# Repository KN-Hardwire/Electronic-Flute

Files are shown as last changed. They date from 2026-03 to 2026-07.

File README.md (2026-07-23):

<div align="center">

# Electronic Flute

### *This repository present HARDWIRE student club [AGH University of Cracow](https://en.wikipedia.org/wiki/AGH_University_of_Krak%C3%B3w) Electronic Flute project.*

---

<a href="https://youtu.be/xWjR7IvugFc" target="_blank">
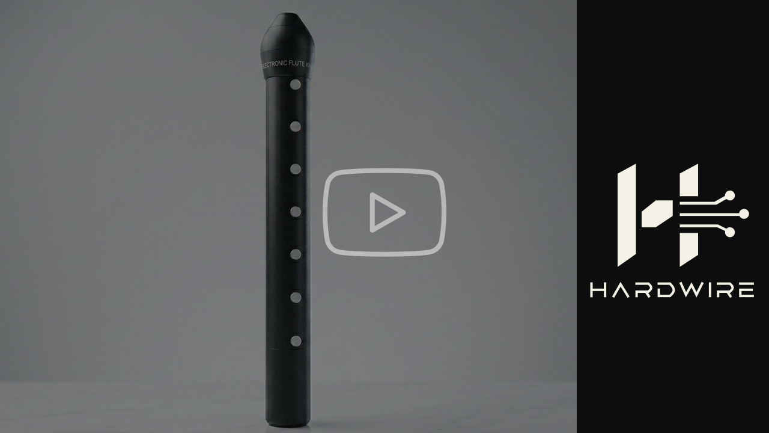
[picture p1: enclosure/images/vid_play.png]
Watch the video
   
</a>
<br />
<em>Watch the video on our YouTube channel to see how it works!</em>

---

</div>

## Programming and assembly

Please refer to guides in each folder for details.

## Playing the flute

All the officially supported note are listed inside the [Fingering Chart](./Fingering_Chart.md), though you should be able to play the instrument just like a standard [recorder flute](https://en.wikipedia.org/wiki/Recorder_(musical_instrument)).

---
<div align="center">
  <sub>Electronic Flute • KN-Hardwire</sub>
</div>

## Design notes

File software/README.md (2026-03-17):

# Software

## Instalation
You can install already compiled firmware on github by going to **Actions**
section and choosing the latest passing commit on the **build** workflow.
There you will find the **'firmware'** binary ready to download.

## Dependencies
- pico-sdk for C/C++ (included as submodule)

## Compilation
To compile the firmware locally you must first:   
Initialize pico-sdk and its submodules:
```
git submodule update --init --recursive
```

Create a build directory and from it run cmake: 
```
mkdir build
cd build
cmake ..
```

There are CMake flags available for easier debugging and development:   
*No debug on default (no flag passed)*
```
-DDEBUG_MODE=<OFF/ON>
```

If succesful, run the Makefile from build directory:
```
make
```

## Flashing
To flash use the SWD Port located on the board.
Use a Rasberry Pi Pico flashed with [debugprobe_on_pico.uf2](https://github.com/raspberrypi/debugprobe/releases)
and make a connection as follows:
| Pico | Flute |
| --- | --- |
| GND | GND |
| CLK | GP2 |
| S_IO | GP3 |

Alternatively you can use a dedicated Rasberry Pi Debugprobe.

Then to upload the code, **with the 3V battery installed**, inside build folder run:
```
make flash
```

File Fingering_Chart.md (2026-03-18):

# Electronic Flute Fingering Chart

This document outlines the recognized fingerings for the Electronic flute project. Because this hardware uses simple on/off switches (buttons) instead of acoustic tone holes, acoustic techniques like "half-holing" are not possible. Instead, specific **cross-fingerings** and alternative combinations are hardcoded to produce sharps, flats, and higher register notes.

## Legend
* **⚫** = Button Pressed (Hole Closed)
* **⚪** = Button Unpressed (Hole Open)

*Note: In the hardware logic, a pressed button pulls the GPIO LOW (`0`), and an unpressed button is pulled HIGH (`1`).*

---

## Recognized Note Combinations

Below is the complete list of exact hardware combinations mapped to frequencies. Any "sloppy" finger transitions between these states are banded to the nearest note in the software to prevent glitches.

<table>
  <thead>
	<tr>
	  <th>Note (Intl.)</th>
	  <th style="border-right: 2px solid #777;">Back</th>
	  <th colspan="3" style="border-right: 2px solid #777;">Left Hand</th>
	  <th colspan="4">Right Hand</th>
	</tr>
	<tr>
	  <th></th>
	  <th style="border-right: 2px solid #777;">Thumb</th>
	  <th>Index</th>
	  <th>Middle</th>
	  <th style="border-right: 2px solid #777;">Ring</th>
	  <th>Index</th>
	  <th>Middle</th>
	  <th>Ring</th>
	  <th>Pinky</th>
	</tr>
  </thead>
  <tbody>
	<tr>
	  <td><b>C4</b></td>
	  <td align="center" style="border-right: 2px solid #777;">⚫</td>
	  <td align="center">⚫</td>
	  <td align="center">⚫</td>
	  <td align="center" style="border-right: 2px solid #777;">⚫</td>
	  <td align="center">⚫</td>
	  <td align="center">⚫</td>
	  <td align="center">⚫</td>
	  <td align="center">⚫</td>
	</tr>
	<tr>
	  <td><b>C#4 / Db4</b></td>
	  <td align="center" style="border-right: 2px solid #777;">⚫</td>
	  <td align="center">⚫</td>
	  <td align="center">⚫</td>
	  <td align="center" style="border-right: 2px solid #777;">⚫</td>
	  <td align="center">⚫</td>
	  <td align="center">⚫</td>
	  <td align="center">⚪</td>
	  <td align="center">⚫</td>
	</tr>
	<tr>
	  <td><b>D4</b></td>
	  <td align="center" style="border-right: 2px solid #777;">⚫</td>
	  <td align="center">⚫</td>
	  <td align="center">⚫</td>
	  <td align="center" style="border-right: 2px solid #777;">⚫</td>
	  <td align="center">⚫</td>
	  <td align="center">⚫</td>
	  <td align="center">⚫</td>
	  <td align="center">⚪</td>
	</tr>
	<tr>
	  <td><b>D#4 / Eb4</b></td>
	  <td align="center" style="border-right: 2px solid #777;">⚫</td>
	  <td align="center">⚫</td>
	  <td align="center">⚫</td>
	  <td align="center" style="border-right: 2px solid #777;">⚫</td>
	  <td align="center">⚫</td>
	  <td align="center">⚪</td>
	  <td align="center">⚫</td>
	  <td align="center">⚪</td>
	</tr>
	<tr>
	  <td><b>E4</b></td>
	  <td align="center" style="border-right: 2px solid #777;">⚫</td>
	  <td align="center">⚫</td>
	  <td align="center">⚫</td>
	  <td align="center" style="border-right: 2px solid #777;">⚫</td>
	  <td align="center">⚫</td>
	  <td align="center">⚫</td>
	  <td align="center">⚪</td>
	  <td align="center">⚪</td>
	</tr>
	<tr>
	  <td><b>F4</b></td>
	  <td align="center" style="border-right: 2px solid #777;">⚫</td>
	  <td align="center">⚫</td>
	  <td align="center">⚫</td>
	  <td align="center" style="border-right: 2px solid #777;">⚫</td>
	  <td align="center">⚫</td>
	  <td align="center">⚪</td>
	  <td align="center">⚪</td>
	  <td align="center">⚪</td>
	</tr>
	<tr>
	  <td><b>F#4 / Gb4</b></td>
	  <td align="center" style="border-right: 2px solid #777;">⚫</td>
	  <td align="center">⚫</td>
	  <td align="center">⚫</td>
	  <td align="center" style="border-right: 2px solid #777;">⚫</td>
	  <td align="center">⚪</td>
	  <td align="center">⚫</td>
	  <td align="center">⚪</td>
	  <td align="center">⚪</td>
	</tr>
	<tr>
	  <td><b>G4</b></td>
	  <td align="center" style="border-right: 2px solid #777;">⚫</td>
	  <td align="center">⚫</td>
	  <td align="center">⚫</td>
	  <td align="center" style="border-right: 2px solid #777;">⚫</td>
	  <td align="center">⚪</td>
	  <td align="center">⚪</td>
	  <td align="center">⚪</td>
	  <td align="center">⚪</td>
	</tr>
	<tr>
	  <td><b>G#4 / Ab4</b></td>
	  <td align="center" style="border-right: 2px solid #777;">⚫</td>
	  <td align="center">⚫</td>
	  <td align="center">⚫</td>
	  <td align="center" style="border-right: 2px solid #777;">⚪</td>
	  <td align="center">⚫</td>
	  <td align="center">⚫</td>
	  <td align="center">⚫</td>
	  <td align="center">⚪</td>
	</tr>
	<tr>
	  <td><b>A4</b></td>
	  <td align="center" style="border-right: 2px solid #777;">⚫</td>
	  <td align="center">⚫</td>
	  <td align="center">⚫</td>
	  <td align="center" style="border-right: 2px solid #777;">⚪</td>
	  <td align="center">⚪</td>
	  <td align="center">⚪</td>
	  <td align="center">⚪</td>
	  <td align="center">⚪</td>
	</tr>
	<tr>
	  <td><b>A#4 / Bb4</b></td>
	  <td align="center" style="border-right: 2px solid #777;">⚫</td>
	  <td align="center">⚫</td>
	  <td align="center">⚫</td>
	  <td align="center" style="border-right: 2px solid #777;">⚪</td>
	  <td align="center">⚫</td>
	  <td align="center">⚪</td>
	  <td align="center">⚪</td>
	  <td align="center">⚪</td>
	</tr>
	<tr>
	  <td><b>B4</b></td>
	  <td align="center" style="border-right: 2px solid #777;">⚫</td>
	  <td align="center">⚫</td>
	  <td align="center">⚪</td>
	  <td align="center" style="border-right: 2px solid #777;">⚪</td>
	  <td align="center">⚪</td>
	  <td align="center">⚪</td>
	  <td align="center">⚪</td>
	  <td align="center">⚪</td>
	</tr>
	<tr>
	  <td><b>C5</b></td>
	  <td align="center" style="border-right: 2px solid #777;">⚫</td>
	  <td align="center">⚪</td>
	  <td align="center">⚫</td>
	  <td align="center" style="border-right: 2px solid #777;">⚪</td>
	  <td align="center">⚪</td>
	  <td align="center">⚪</td>
	  <td align="center">⚪</td>
	  <td align="center">⚪</td>
	</tr>
	<tr>
	  <td><b>C#5 / Db5</b></td>
	  <td align="center" style="border-right: 2px solid #777;">⚫</td>
	  <td align="center">⚪</td>
	  <td align="center">⚪</td>
	  <td align="center" style="border-right: 2px solid #777;">⚪</td>
	  <td align="center">⚪</td>
	  <td align="center">⚪</td>
	  <td align="center">⚪</td>
	  <td align="center">⚪</td>
	</tr>
	<tr>
	  <td><b>D5</b></td>
	  <td align="center" style="border-right: 2px solid #777;">⚪</td>
	  <td align="center">⚪</td>
	  <td align="center">⚫</td>
	  <td align="center" style="border-right: 2px solid #777;">⚪</td>
	  <td align="center">⚪</td>
	  <td align="center">⚪</td>
	  <td align="center">⚪</td>
	  <td align="center">⚪</td>
	</tr>
	<tr>
	  <td><b>D#5 / Eb5</b></td>
	  <td align="center" style="border-right: 2px solid #777;">⚪</td>
	  <td align="center">⚫</td>
	  <td align="center">⚫</td>
	  <td align="center" style="border-right: 2px solid #777;">⚫</td>
	  <td align="center">⚫</td>
	  <td align="center">⚫</td>
	  <td align="center">⚫</td>
	  <td align="center">⚪</td>
	</tr>
	<tr>
	  <td><b>E5</b></td>
	  <td align="center" style="border-right: 2px solid #777;">⚪</td>
	  <td align="center">⚫</td>
	  <td align="center">⚫</td>
	  <td align="center" style="border-right: 2px solid #777;">⚫</td>
	  <td align="center">⚫</td>
	  <td align="center">⚫</td>
	  <td align="center">⚪</td>
	  <td align="center">⚪</td>
	</tr>
  </tbody>
</table>

### Alternative Fingerings
These combinations are also recognized by the software to allow for different playing styles or specific trills.

<table>
  <thead>
	<tr>
	  <th>Note (Intl.)</th>
	  <th style="border-right: 2px solid #777;">Back</th>
	  <th colspan="3" style="border-right: 2px solid #777;">Left Hand</th>
	  <th colspan="4">Right Hand</th>
	</tr>
	<tr>
	  <th></th>
	  <th style="border-right: 2px solid #777;">Thumb</th>
	  <th>Index</th>
	  <th>Middle</th>
	  <th style="border-right: 2px solid #777;">Ring</th>
	  <th>Index</th>
	  <th>Middle</th>
	  <th>Ring</th>
	  <th>Pinky</th>
	</tr>
  </thead>
  <tbody>
	<tr>
	  <td><b>C5 (Alt)</b></td>
	  <td align="center" style="border-right: 2px solid #777;">⚪</td>
	  <td align="center">⚪</td>
	  <td align="center">⚪</td>
	  <td align="center" style="border-right: 2px solid #777;">⚪</td>
	  <td align="center">⚪</td>
	  <td align="center">⚪</td>
	  <td align="center">⚪</td>
	  <td align="center">⚪</td>
	</tr>
	<tr>
	  <td><b>B5 (Alt)</b></td>
	  <td align="center" style="border-right: 2px solid #777;">⚪</td>
	  <td align="center">⚪</td>
	  <td align="center">⚫</td>
	  <td align="center" style="border-right: 2px solid #777;">⚫</td>
	  <td align="center">⚫</td>
	  <td align="center">⚫</td>
	  <td align="center">⚫</td>
	  <td align="center">⚫</td>
	</tr>
  </tbody>
</table>

---
**Tip for Builders:** If you are translating these combinations into the raw `button_mask` integer (0-255) for the C array, treat the Thumb as Bit 7 and the Left Index as Bit 0. (e.g., C4 = `0`, D4 = `64`, E4 = `96`, etc.)

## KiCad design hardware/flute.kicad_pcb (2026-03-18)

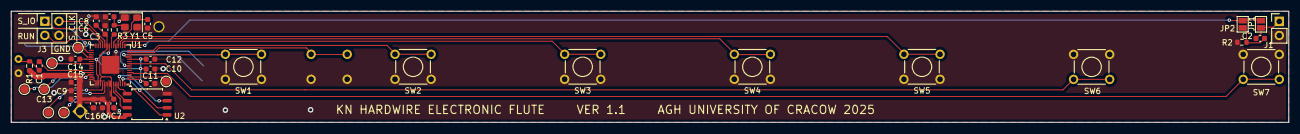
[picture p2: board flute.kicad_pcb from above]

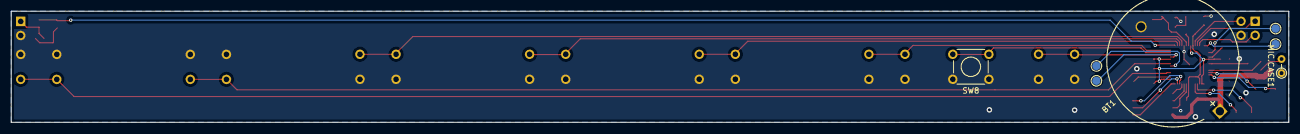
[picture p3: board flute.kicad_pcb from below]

Board: 2 copper layers, 230.0 x 20.0 mm, 47 parts (7 on the bottom side), 39 nets.

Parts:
BT1: Battery_Cell; BatteryHolder_MYOUNG_BS-07-A1BJ001_CR2032
C1, C2, C3, C10: 1uF; C_0603_1608Metric
C4, C7, C8, C9, C11, C12, C13, C14, C15, C16: 0.1uF; C_0603_1608Metric
C5, C6: 15pF; C_0603_1608Metric
J1: Conn_01x02; PinHeader_1x02_P2.54mm_Vertical
J3: Conn_01x04; PinHeader_2x02_P2.54mm_Vertical
JP1: COUPLING; SolderJumper-2_P1.3mm_Open_Pad1.0x1.5mm
JP2: NO_COUPLING; SolderJumper-2_P1.3mm_Open_Pad1.0x1.5mm
MIC.CASE1: R; R_Axial_DIN0204_L3.6mm_D1.6mm_P2.54mm_Vertical
R1: 2.2K; R_0603_1608Metric
R2: 100k; R_0603_1608Metric
R3: 1k; R_0603_1608Metric
SW1: C; SW_TH_Tactile_Omron_B3F-100x
SW2: D; SW_TH_Tactile_Omron_B3F-100x
SW3: E; SW_TH_Tactile_Omron_B3F-100x
SW4: F; SW_TH_Tactile_Omron_B3F-100x
SW5: G; SW_TH_Tactile_Omron_B3F-100x
SW6: A; SW_TH_Tactile_Omron_B3F-100x
SW7: H; SW_TH_Tactile_Omron_B3F-100x
SW8: OCTAVE?; SW_TH_Tactile_Omron_B3F-100x
TP2, TP3, TP4, TP5, TP6, TP7, TP8, TP9, TP10, TP11, TP12: TestPoint; TestPoint_Pad_D1.5mm
U1: RP2040; QFN-56-1EP_7x7mm_P0.4mm_EP3.2x3.2mm
U2: W25Q128JVS; SOIC-8_5.3x5.3mm_P1.27mm
Y1: Crystal_GND24; Crystal_SMD_Abracon_ABM8G-4Pin_3.2x2.5mm

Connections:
+1V1: C3.2, C7.1, C8.1, U1.23 (DVDD), U1.45 (VREG_VOUT), U1.50 (DVDD)
+3V3: BT1.1 (+), C4.2, C9.1, C10.1, C11.1, C12.1, C13.1, C14.1, C15.1, C16.1, R1.2, U1.1 (IOVDD), U1.10 (IOVDD), U1.22 (IOVDD), U1.33 (IOVDD), U1.42 (IOVDD), U1.43 (ADC_AVDD), U1.44 (VREG_IN), U1.48 (USB_VDD), U1.49 (IOVDD), U2.8 (VCC)
/KEY_A: SW6.2, U1.8 (GPIO6)
/KEY_C: SW1.2, U1.12 (GPIO9)
/KEY_D: SW2.2, U1.14 (GPIO11)
/KEY_E: SW3.2, U1.16 (GPIO13)
/KEY_F: SW4.2, U1.17 (GPIO14)
/KEY_G: SW5.2, U1.18 (GPIO15)
/KEY_H: SW7.2, U1.4 (GPIO2)
/KEY_OCTAVE: SW8.2, U1.13 (GPIO10)
/MIC_OUTPUT: C1.2, U1.38 (GPIO26_ADC0)
/PWM_OUT: JP1.2 (B), JP2.2 (B), U1.15 (GPIO12)
/RASPBERRY_PI_PICO/QSPI_CS: U1.56 (QSPI_SS), U2.1 (~CS)
/RASPBERRY_PI_PICO/QSPI_SCLK: U1.52 (QSPI_SCLK), U2.6 (CLK)
/RASPBERRY_PI_PICO/QSPI_SD0: U1.53 (QSPI_SD0), U2.5 (DI/IO_{0})
/RASPBERRY_PI_PICO/QSPI_SD1: U1.55 (QSPI_SD1), U2.2 (DO/IO_{1})
/RASPBERRY_PI_PICO/QSPI_SD2: U1.54 (QSPI_SD2), U2.3 (~WP/IO_{2})
/RASPBERRY_PI_PICO/QSPI_SD3: U1.51 (QSPI_SD3), U2.7 (~HOLD/~RESET/IO_{3})
/RASPBERRY_PI_PICO/RUN: J3.3, U1.26 (RUN)
/RASPBERRY_PI_PICO/SWCLK: J3.2, U1.24 (SWCLK)
/RASPBERRY_PI_PICO/SWDIO: J3.1, U1.25 (SWD)
/RASPBERRY_PI_PICO/USB_DM: TP4.1, U1.46 (USB_DM)
/RASPBERRY_PI_PICO/USB_DP: TP3.1, U1.47 (USB_DP)
/RASPBERRY_PI_PICO/XIN: C5.1, U1.20 (XIN), Y1.1
/RASPBERRY_PI_PICO/XOUT: R3.1, U1.21 (XOUT)
GND: BT1.2 (-), C3.1, C4.1, C5.2, C6.2, C7.2, C8.2, C9.2, C10.2, C11.2, C12.2, C13.2, C14.2, C15.2, C16.2, J1.2, J3.4, MIC.CASE1.1, R2.2, SW1.1, SW2.1, SW3.1, SW4.1, SW5.1, SW6.1, SW7.1, SW8.1, U1.19 (TESTEN), U1.57 (GND), U2.4 (GND), Y1.2, Y1.4
unnamed: C1.1, MIC.CASE1.2, R1.1
unnamed: C6.1, R3.2, Y1.3
unnamed: C2.1, J1.1, JP2.1 (A)
unnamed: C2.2, JP1.1 (A), R2.1
unnamed: TP2.1, U1.2 (GPIO0)
unnamed: TP5.1, U1.7 (GPIO5)
unnamed: TP6.1, U1.11 (GPIO8)
unnamed: TP7.1, U1.28 (GPIO17)
unnamed: TP8.1, U1.30 (GPIO19)
unnamed: TP9.1, U1.32 (GPIO21)
unnamed: TP10.1, U1.35 (GPIO23)
unnamed: TP11.1, U1.39 (GPIO27_ADC1)
unnamed: TP12.1, U1.40 (GPIO28_ADC2)

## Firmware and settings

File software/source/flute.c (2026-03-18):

#include "functions.h"
#include "notes.h"

int main(void) {
    #if DEBUG_MODE == 1
	    stdio_init_all();
    #endif

    const uint16_t buttons[BUTTON_COUNT] = {BUTTON1, BUTTON2, BUTTON3, BUTTON4, BUTTON5, BUTTON6, BUTTON7, BUTTON8};

    for (register uint8_t i = 0; i < BUTTON_COUNT; ++i) {
		gpio_init(buttons[i]);
		gpio_set_dir(buttons[i], GPIO_IN);
		gpio_pull_up(buttons[i]);
    }

    adc_init();
    adc_gpio_init(ADC26);
    adc_select_input(0);

	gpio_init(OUT_PIN);
    gpio_set_function(OUT_PIN, GPIO_FUNC_PWM);

    uint8_t button_mask;

    while (true) {
		button_mask = 0;
		for (register uint8_t i = 0; i < BUTTON_COUNT; ++i) {
			if (gpio_get(buttons[i])) {
				button_mask |= (1 << i);
			}
		}

		generate_square_wave(mask_freq[button_mask], lowpass_iir(get_volume()));
	}

    return EXIT_SUCCESS;
}

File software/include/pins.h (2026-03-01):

#ifndef PINS_H
#define PINS_H

// Pin Configuration for Electronic Flute
#define BUTTON1     ((uint8_t) 9)   // SW1 / KEY_C
#define BUTTON2     ((uint8_t) 11)  // SW2 / KEY_D
#define BUTTON3     ((uint8_t) 13)  // SW3 / KEY_E
#define BUTTON4     ((uint8_t) 14)  // SW4 / KEY_F
#define BUTTON5     ((uint8_t) 15)  // SW5 / KEY_G
#define BUTTON6     ((uint8_t) 6)   // SW6 / KEY_A
#define BUTTON7     ((uint8_t) 2)   // SW7 / KEY_H
#define BUTTON8     ((uint8_t) 10)  // SW8 / KEY_OCTAVE

#define ADC26       ((uint8_t) 26)  // Microphone ADC input
#define OUT_PIN     ((uint8_t) 12)  // Audio PWM output

#endif // PINS_H

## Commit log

2026-02-23 standardise mask infinite loop bug fix
    [functions.c]
2026-02-24 slow down work to reduce power consumed
2026-02-28 pin configuration software <-> hardware
2026-02-28 fix button logic
2026-03-01 fix frequency on all buttons pressed
    [functions.c]
2026-03-18 added frequency for each button combination for real recorder imitation
2026-03-18 added Fingering Chart
2026-03-18 fixed power issues with flash on pcb
    [flute.kicad_pcb, raspberry.kicad_sch]
